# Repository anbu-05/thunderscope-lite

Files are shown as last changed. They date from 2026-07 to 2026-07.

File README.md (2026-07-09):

ad9288 can be replaced with ad9218 for higher resolution

the AFE is designed for 1GSPS so 100MSPS should work just fine

the STM32H523RETx can be replaced with STM32H562RGTx for higher performance

also you NEED to implement the microcontroller IC in the PCB because you need to make sure the all 8/10 of the ADC's output signals arrive at the same time

ad9288/9218 have different sampling rate options - but this requires changing out the CMOS oscillator accordinly as well. the current option is for a low jitter 100MHz clk signal: ASEM1-100.000MHZ-LC-T

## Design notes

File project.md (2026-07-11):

# thunderscope-lite Project Notes

## Current status

- `thunderscope-lite` is a KiCad 9 project at the repo root.
- Custom/project KiCad libraries have been vendored into `thunderscope-lite/libraries/`.
- Local library tables now point the existing schematic library names at the vendored files:
  - `sym-lib-table`
  - `fp-lib-table`
- Standard KiCad libraries such as `Device`, `power`, `Connector`, `Diode`, `Resistor_SMD`, `Capacitor_SMD`, and `Package_TO_SOT_SMD` are still expected from the installed KiCad library set.

## Vendored libraries

- Symbols are in `libraries/symbols/`.
- Footprints are in `libraries/footprints/`.
- Available custom 3D models are in `libraries/3dmodels/`.
- `AD9288BSTZ-40` and `ADA4930-2YCPZ-R2` footprints reference local STEP files through `${KIPRJMOD}`.
- `731000105.zip` and `UD2-4.5NUN-L.zip` do not contain STEP or WRL models, so no 3D models were available for those parts.

## Notes

- The project keeps existing library names like `AD9288BSTZ-40`, `ADA4930-2YCPZ-R2`, `UD2-4.5NUN-L`, `731000105`, and `Thunderscope_Rev5`.
- The `Thunderscope_Rev5` footprint library now contains the full Rev5.3 project footprint set, currently 61 `.kicad_mod` files.
- KiCad lock file `~thunderscope-lite.kicad_sch.lck` existed before this library work and was left alone.
- KiCad ERC was run on 2026-07-07 and completed without missing-library errors. It reported 108 existing schematic ERC violations, mostly unconnected pins and power pins not driven.
- While this was being edited, KiCad appears to have generated/updated autosave files and a backup zip. These were left untouched.
- 2026-07-11: Initial TL33/TL330 search did not find the library. It was later found as `TL3342F160QG.zip` and imported below.

## 2026-07-08 update

- Copied the full Rev5.3 project footprint library from `ThunderScope/Hardware/Thunderscope_Rev5.3/Thunderscope_Rev5.3.pretty/` into `libraries/footprints/Thunderscope_Rev5.pretty/`.
- Refreshed `libraries/symbols/Thunderscope_Rev5.kicad_sym` from Rev5.3.
- The lite project still uses the library name `Thunderscope_Rev5`; only the local library contents were expanded.

## 2026-07-08 STEP model note

- Rev5.3 does not store its 3D models as loose `.step`, `.stp`, or `.wrl` files in the project tree.
- The Rev5.3 3D models are embedded inside the copied `.kicad_mod` footprint files and referenced with `kicad-embed://...`.
- Fixed the lite copy of `FUJ_FTR-B3SA.kicad_mod` to reference its embedded `FTR-B3SA4.5Z.stp` model instead of the old Windows absolute path.

## 2026-07-08 KiCad library visibility note

- Adding `THUNDER_*` path variables in KiCad Configure Paths does not by itself make symbols or footprints appear in the chooser.
- KiCad loads project libraries from `sym-lib-table` and `fp-lib-table` in the project folder.
- Open `thunderscope-lite.kicad_pro`, then use Preferences -> Manage Symbol Libraries / Manage Footprint Libraries and check the Project Specific tab if vendored libraries do not appear.

## 2026-07-08 embedded model question

- Asked whether the AD9288 and AD4390 STEP files can be embedded into their footprint files.
- AD9288 has a loose STEP file in `libraries/3dmodels/`.
- No AD4390 library has been identified in the project; this may mean `ADA4930-2YCPZ-R2`.
- KiCad 9 footprints can embed 3D model files using `embedded_files` and `kicad-embed://...`, as seen in the copied Rev5.3 footprints.

## 2026-07-08 embedded_files format note

- KiCad 9 footprint embedded models are stored in an `(embedded_files ...)` block inside the `.kicad_mod` file.
- Each embedded file uses `(file (name "...") (type ...) (data |...|) (checksum "..."))`.
- The footprint 3D model entry references the embedded payload with `(model "kicad-embed://filename.step" ...)`.

## 2026-07-11 TL3342F160QG import

- Imported `TL3342F160QG.zip` from `/home/anbu/Downloads`.
- Added symbol library: `libraries/symbols/TL3342F160QG.kicad_sym`.
- Added footprint library: `libraries/footprints/TL3342F160QG.pretty/SW_TL3342F160QG.kicad_mod`.
- Added 3D model: `libraries/3dmodels/TL3342F160QG.step`.
- Registered `TL3342F160QG` in project `sym-lib-table` and `fp-lib-table`.
- Added a project-relative STEP model reference to the footprint using `${KIPRJMOD}/libraries/3dmodels/TL3342F160QG.step`.
- KiCad CLI `fp upgrade` parsed the new footprint library successfully. KiCad ERC loads the project without missing-library messages, but the schematic still has existing ERC violations.

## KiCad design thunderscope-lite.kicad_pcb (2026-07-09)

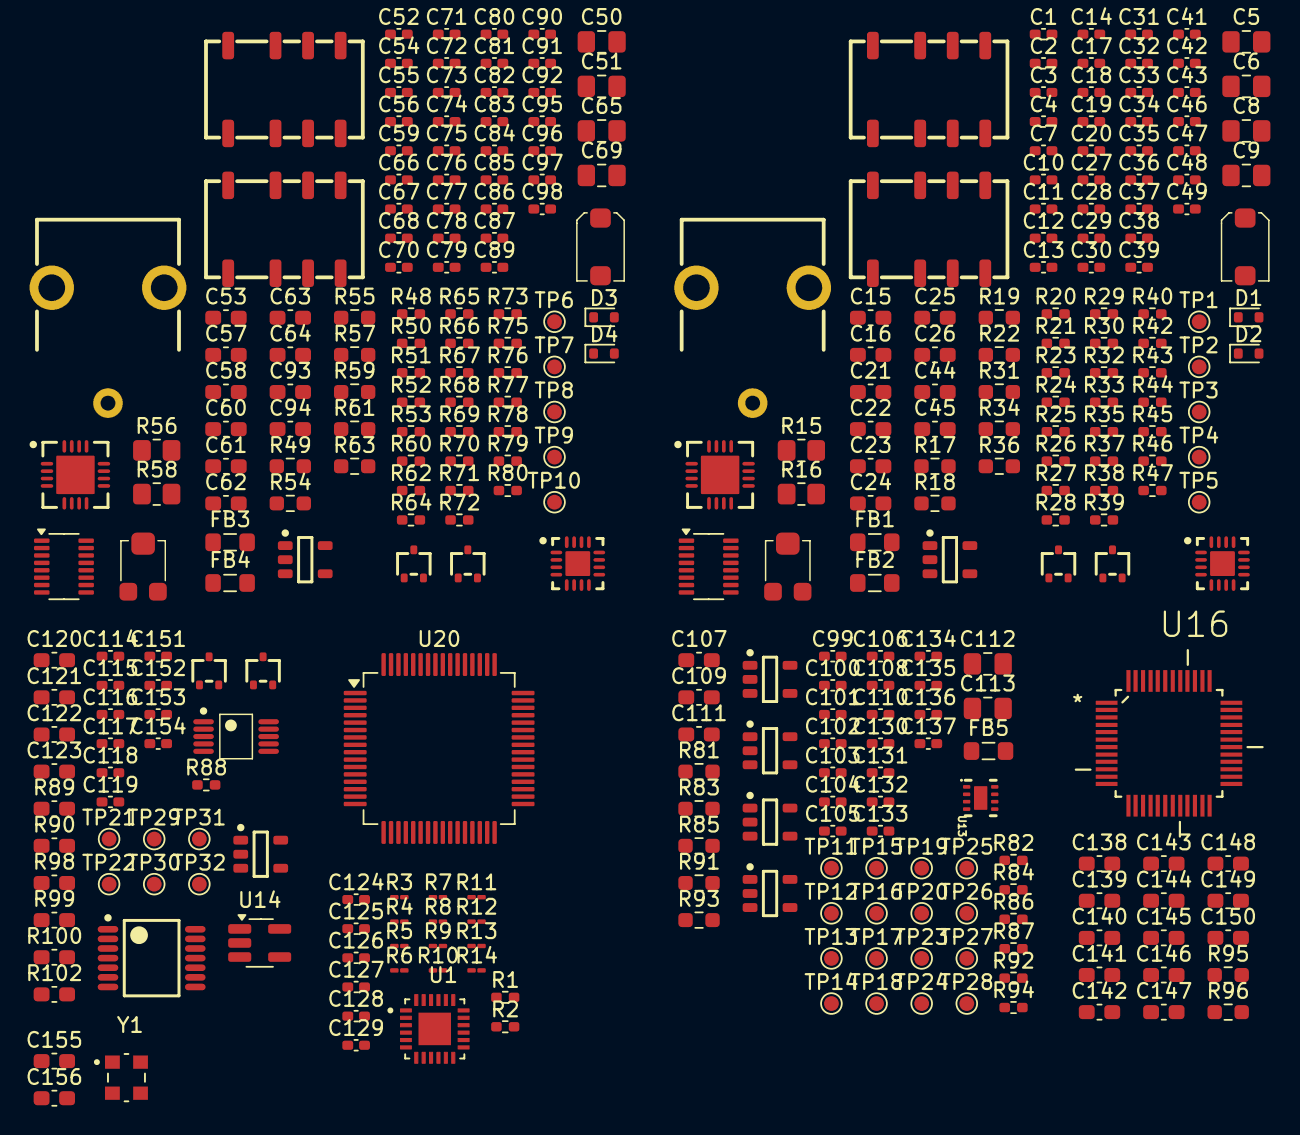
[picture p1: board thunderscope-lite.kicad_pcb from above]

Board: 2 copper layers, 330 parts (0 on the bottom side), 150 nets, no tracks yet.

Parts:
C1, C56: 18pF; C_0402_1005Metric_Pad0.74x0.62mm_HandSolder
C2, C3, C13, C77, C80, C87: 3pF; C_0402_1005Metric_Pad0.74x0.62mm_HandSolder
C4, C81: 0.3pF; C_0402_1005Metric_Pad0.74x0.62mm_HandSolder
C5, C6, C8, C9, C50, C51, C65, C69: 22uF; C_0805_2012Metric_Pad1.18x1.45mm_HandSolder
C7, C10, C27, C28, C29, C30, C31, C32, C33, C34, C35, C36, C37, C38, C39, C46, C47, C48, C49, C52, C66, C67, C70, C71, C72, C73, C74, C75, C76, C78, C79, C82, C83, C85, C95, C96, C97, C98, C101, C102, C105, C106, C115, C116, C117, C124, C125, C126, C127, C128, C132, C133, C136, C137, C152, C154: 1uF; C_0402_1005Metric_Pad0.74x0.62mm_HandSolder
C11, C86: 1pF; C_0402_1005Metric_Pad0.74x0.62mm_HandSolder
C12, C84: 8pF; C_0402_1005Metric_Pad0.74x0.62mm_HandSolder
C14, C41, C42, C43, C89, C90, C91, C92, C118: 100nF; C_0402_1005Metric_Pad0.74x0.62mm_HandSolder
C15, C60: 1nF; C_0603_1608Metric_Pad1.08x0.95mm_HandSolder
C16, C53: 10nF; C_0603_1608Metric_Pad1.08x0.95mm_HandSolder
C17, C18, C20, C54, C59, C68, C119: 100pF; C_0402_1005Metric_Pad0.74x0.62mm_HandSolder
C19, C55: 68pF; C_0402_1005Metric_Pad0.74x0.62mm_HandSolder
C21, C22, C23, C24, C25, C26, C44, C45, C57, C58, C61, C62, C63, C64, C93, C94, C107, C109, C111, C120, C122, C141, C142, C156: 10uF; C_0603_1608Metric_Pad1.08x0.95mm_HandSolder
C40, C88: 2-6pF; EW_TRIMCAP
C99, C100, C103, C104, C108, C110, C114, C129, C130, C131, C134, C135, C151, C153: 10uF; C_0402_1005Metric_Pad0.74x0.62mm_HandSolder
C112, C113: 10uF; C_0805_2012Metric_Pad1.18x1.45mm_HandSolder
C121, C123: 1uF; C_0603_1608Metric_Pad1.08x0.95mm_HandSolder
C138, C139, C140, C143, C144, C145, C146, C147, C148, C149, C150: 100nF; C_0603_1608Metric_Pad1.08x0.95mm_HandSolder
C155: 0.1uF; C_0603_1608Metric_Pad1.08x0.95mm_HandSolder
D1, D2, D3, D4: 1N4148WT; D_SOD-523
FB1, FB2, FB3, FB4, FB5: 120@100MHZ; L_0805_2012Metric_Pad1.05x1.20mm_HandSolder
J1, J2: BNC; MOL_0731000105
K1, K2, K3, K4: UD2-4.5NUN-L; KEMET_UD2-4.5NUN-L
Q1, Q2, Q3, Q4, Q5, Q6: DMN62D0UW; GEN_SOT_323
R1, R2: 300R; R_0402_1005Metric_Pad0.72x0.64mm_HandSolder
R3, R4, R5, R6, R7, R8: 300R; R_01005_0402Metric_Pad0.57x0.30mm_HandSolder
R9, R10: 120R; R_01005_0402Metric_Pad0.57x0.30mm_HandSolder
R11, R12, R13, R14: 4.99R; R_01005_0402Metric_Pad0.57x0.30mm_HandSolder
R15, R56: 49.9R; R_0805_2012Metric_Pad1.20x1.40mm_HandSolder
R16, R58: 1MR; R_0805_2012Metric_Pad1.20x1.40mm_HandSolder
R17, R31, R55, R57: 30R; R_0603_1608Metric_Pad0.98x0.95mm_HandSolder
R18, R59: 15R; R_0603_1608Metric_Pad0.98x0.95mm_HandSolder
R19, R22, R49, R63: 22R; R_0603_1608Metric_Pad0.98x0.95mm_HandSolder
R20, R21, R23, R24, R52, R53, R64, R65: 10KR; R_0402_1005Metric_Pad0.72x0.64mm_HandSolder
R25, R46, R47, R60, R79, R80: 0R; R_0402_1005Metric_Pad0.72x0.64mm_HandSolder
R26, R43, R44, R66, R76, R77: 1K; R_0402_1005Metric_Pad0.72x0.64mm_HandSolder
R27, R28, R67, R68: 976K; R_0402_1005Metric_Pad0.72x0.64mm_HandSolder
R29, R70: 20K; R_0402_1005Metric_Pad0.72x0.64mm_HandSolder
R30, R50: 909K; R_0402_1005Metric_Pad0.72x0.64mm_HandSolder
R32, R38, R40, R51, R71, R75, R87: 90.9K; R_0402_1005Metric_Pad0.72x0.64mm_HandSolder
R33, R39, R45, R48, R72, R78, R82, R84, R92, R94: 10K; R_0402_1005Metric_Pad0.72x0.64mm_HandSolder
R34, R36, R54, R61: 10M; R_0603_1608Metric_Pad0.98x0.95mm_HandSolder
R35, R62: 2K; R_0402_1005Metric_Pad0.72x0.64mm_HandSolder
R37, R69: 35.7K; R_0402_1005Metric_Pad0.72x0.64mm_HandSolder
R41, R74: 2K TRIMPOT; BOU_3mm_POT
R42, R73: 49.9K; R_0402_1005Metric_Pad0.72x0.64mm_HandSolder
R81, R83, R85, R91, R93: 0.01R; R_0603_1608Metric_Pad0.98x0.95mm_HandSolder
R86: 280K; R_0402_1005Metric_Pad0.72x0.64mm_HandSolder
R88: 100R; R_0402_1005Metric_Pad0.72x0.64mm_HandSolder
R89, R90: 10K; C_0603_1608Metric_Pad1.08x0.95mm_HandSolder
R95: 23.2K; R_0603_1608Metric_Pad0.98x0.95mm_HandSolder
R96: 10K; R_0603_1608Metric_Pad0.98x0.95mm_HandSolder
R98, R99, R100, R102: 4.7K; C_0603_1608Metric_Pad1.08x0.95mm_HandSolder
TP1, TP2, TP3, TP4, TP5, TP6, TP7, TP8, TP9, TP10, TP11, TP12, TP13, TP14, TP15, TP16, TP17, TP18, TP19, TP20, TP21, TP22, TP23, TP24, TP25, TP26, TP27, TP28, TP29, TP30, TP31, TP32: TestPoint; TestPoint_Pad_D1.0mm
U1: ADA4930-2YCPZ-R2; QFN50P400X400X100-25N
U2: MCP4728; MC_MSOP10_UN
U3, U7: TMUX4053; TI_TSOT-23-16_DYY0016A
U4, U8, U15: OPA140AIDBVR; GEN_SOT23_5_950_2900X1600X1450
U5, U9: BUF802; TI_VQFN_RGT0016C
U6, U10: LMH6518; TI_WQFN_RGH0016A
U11, U12, U17, U18: NCP161ASN330T1G; GEN_SOT23_5_950_2900X1600X1450
U13: LM27761; TI_WSON8_DSG0008A
U14: REF2025; SOT-23-5_HandSoldering
U16: AD9218BSTZ-105; QFP50P900X900X160-48N
U19: MCP4452-104E; MC_TSSOP14
U20: STM32H562RGTx; LQFP-64_10x10mm_P0.5mm
Y1: ASEM1-100.000MHZ-LC-T; XTAL_ASEM1-100.000MHZ-LC-T

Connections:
+3V3_ACQ: C101.1, C102.1, C126.1, C127.1, C128.1, C129.1, TP13.1, U1.3 (+VS1), U1.4 (+VS1), U1.9 (+VS2), U1.10 (+VS2), U1.14 (*PD2), U1.20 (*PD1), U11.5 (OUT)
+3V3_PGA: C49.2, C98.2, Q3.2 (G), Q4.2 (G), R45.2, R78.2, R99.1, R100.1, U6.12 (VDD), U10.12 (VDD)
+3V3_VD: C132.1, C133.1, C142.2, C144.2, C146.2, C148.2, C150.2, R95.1, TP25.1, U16.13 (VD_2), U16.30 (VD_3), U16.31 (VD), U16.48 (VD_4), U17.5 (OUT)
+3V3_VDD: C136.1, C137.1, C141.1, C143.1, C145.1, C147.1, C149.1, C155.1, C156.1, TP28.1, U16.15 (VDD), U16.28 (VDD_3), U16.33 (VDD_2), U16.46 (VDD_4), U18.5 (OUT), Y1.1 (STANDBY), Y1.4 (VDD)
+5V: C5.1, C8.1, C21.2, C22.2, C23.2, C27.2, C28.2, C29.2, C30.2, C31.2, C32.2, C39.2, C44.2, C50.1, C57.2, C61.2, C63.2, C65.1, C66.2, C70.2, C73.2, C75.2, C78.2, C82.2, C85.2, C93.2, C114.1, C115.1, C120.1, C121.1, C151.1, C152.1, C153.1, C154.1, FB2.1, FB4.1, R19.1, R22.1, R49.1, R63.1, R81.1, R83.1, R85.1, R91.1, R93.1, R98.1, R102.1, TP11.1, TP14.1, TP17.1, TP23.1, TP26.1, U2.1 (VDD), U3.16 (VDD), U4.5 (V+), U5.1 (Vs+), U5.12 (Vso+), U5.15 (CLH), U7.16 (VDD), U8.5 (V+), U9.1 (Vs+), U9.12 (Vso+), U9.15 (CLH), U14.3 (EN), U14.4 (IN), U15.5 (V+), U19.12 (VDD)
+VBIAS: C117.1, R89.2, TP21.1, U14.5 (Vref)
-5V: C24.1, C25.1, C26.1, C33.1, C34.1, C35.1, C36.1, C37.1, C38.1, C58.1, C62.1, C64.1, C67.1, C71.1, C74.1, C76.1, C79.1, C83.1, C110.1, C112.1, C113.1, C122.2, C123.2, FB5.2, R37.1, R69.1, TP20.1, U3.7 (VSS), U4.2 (V-), U5.5 (Vs-), U5.6 (Aux_Bias), U5.8 (Vs-), U5.10 (Vso-), U7.7 (VSS), U8.2 (V-), U9.5 (Vs-), U9.6 (Aux_Bias), U9.8 (Vs-), U9.10 (Vso-), U15.2 (V-)
-VBIAS: C14.2, C41.2, C89.2, C91.2, C118.1, R40.1, R43.2, R44.2, R75.1, R76.2, R77.2, R88.1, TP22.1
/ACQ and FE Voltage Regs/+5V_R_CP: C107.1, R85.2, TP18.1, U13.1 (VIN)
/ACQ and FE Voltage Regs/ACQ_EN: R82.2, U11.3 (EN)
/ACQ and FE Voltage Regs/PGA_EN: R84.2, U12.3 (EN)
/ACQ and FE Voltage Regs/VDD_EN: R94.2, U18.3 (EN)
/ACQ and FE Voltage Regs/VD_EN: R92.2, U17.3 (EN)
/ADC driver/IN1_N: R3.1, R9.1, R47.1
/ADC driver/IN1_P: R2.1, R9.2, R46.1
/ADC driver/IN2_N: R7.1, R10.1, R80.1
/ADC driver/IN2_P: R6.1, R10.2, R79.1
/ADC driver/OUT1_N: R11.2, U16.3 (~AINA)
/ADC driver/OUT1_P: R12.2, U16.2 (AINA)
/ADC driver/OUT2_N: R13.2, U16.10 (~AINB)
/ADC driver/OUT2_P: R14.2, U16.11 (AINB)
/ADC/ENC: U16.14 (ENCB), U16.47 (ENCA), Y1.3 (OUTPUT)
/CH1/+VPGA: C45.2, C46.2, C47.2, C48.2, FB2.2, U6.3 (VCC), U6.4 (VCC)
/CH1/ATTEN: R23.2, R24.1, TP2.1
/CH1/ATTEN_1X: K1.4, K1.5
/CH1/ATTEN_50X_IN: C3.2, C4.2, K1.2, R26.2, R27.2
/CH1/ATTEN_50X_OUT: C11.1, C13.1, C40.1, K1.7, R27.1, R29.1
/CH1/ATTEN_IN: K1.3, K3.6
/CH1/ATTEN_OUT: K1.6, R30.2, R31.1
/CH1/BNC_IN: J2.1 (Signal), K3.3
/CH1/BUF_IN: C15.2, R36.1, U5.2 (IN)
/CH1/BUF_IN_AUX: C20.2, R35.2, U5.4 (IN_Aux)
/CH1/BUF_IN_BIAS: R36.2, U5.3 (IN_Bias)
/CH1/BUF_OUT: R38.2, R42.2, U5.11 (OUT)
/CH1/BUF_OUT_R: R42.1, U6.6 (IN_P)
/CH1/DC_CPL: R33.2, TP3.1, U3.9 (SEL3), U3.10 (SEL2), U3.11 (SEL1)
/CH1/DC_FB: C17.1, U3.15 (D2), U4.4 (-)
/CH1/PGA_BIAS: C43.2, FB1.2, R43.1, R44.1, TP4.1, U6.7 (IN_N)
/CH1/PGA_CSn: R45.1, TP5.1, U6.9 (CSn)
/CH1/TERM: R20.1, R21.2, TP1.1
/CH1/TERM_1M: K3.2, R17.1
/CH1/TERM_50Z: C1.1, K3.4, R15.1, R18.1
/CH1/TERM_50Z_R: K3.5, R18.2, R25.2
/CH2/+VPGA: C94.2, C95.2, C96.2, C97.2, FB4.2, U10.3 (VCC), U10.4 (VCC)
/CH2/ATTEN: R64.2, R65.1, TP8.1
/CH2/ATTEN_1X: K4.4, K4.5
/CH2/ATTEN_50X_IN: C80.2, C81.2, K4.2, R66.2, R67.2
/CH2/ATTEN_50X_OUT: C86.1, C87.1, C88.1, K4.7, R67.1, R70.1
/CH2/ATTEN_IN: K2.6, K4.3
/CH2/ATTEN_OUT: K4.6, R50.2, R57.1
/CH2/BNC_IN: J1.1 (Signal), K2.3
/CH2/BUF_IN: C60.2, R61.1, U9.2 (IN)
/CH2/BUF_IN_AUX: C68.2, R62.2, U9.4 (IN_Aux)
/CH2/BUF_IN_BIAS: R61.2, U9.3 (IN_Bias)
/CH2/BUF_OUT: R71.2, R73.2, U9.11 (OUT)
/CH2/BUF_OUT_R: R73.1, U10.6 (IN_P)
/CH2/DC_CPL: R48.2, TP6.1, U7.9 (SEL3), U7.10 (SEL2), U7.11 (SEL1)
/CH2/DC_FB: C59.1, U7.15 (D2), U8.4 (-)
/CH2/PGA_BIAS: C92.2, FB3.2, R76.1, R77.1, TP10.1, U10.7 (IN_N)
/CH2/PGA_CSn: R78.1, TP9.1, U10.9 (CSn)
/CH2/TERM: R52.2, R53.1, TP7.1
/CH2/TERM_1M: K2.2, R55.1
/CH2/TERM_50Z: C56.1, K2.4, R56.1, R59.1
/CH2/TERM_50Z_R: K2.5, R59.2, R60.2
/Front End Trim and Bias/TRIM_SCL: Q4.3 (S), R99.2, TP31.1
/Front End Trim and Bias/TRIM_SCL_5V: Q4.1 (D), R102.2, TP29.1, U2.2 (SCL), U19.4 (SCL)
/Front End Trim and Bias/TRIM_SDA: Q3.3 (S), R100.2, TP32.1
/Front End Trim and Bias/TRIM_SDA_5V: Q3.1 (D), R98.2, TP30.1, U2.3 (SDA), U19.5 (SDA)
/Front End Trim and Bias/US-: C119.1, R89.1, R90.2, U15.3 (+)
/Front End Trim and Bias/VOUT1: U2.6 (VOUTA), U19.13 (P2B)
/Front End Trim and Bias/VOUT2: U2.7 (VOUTB), U19.10 (P0B)
/Front End Trim and Bias/VOUT3: U2.8 (VOUTC), U19.7 (P1B)
/Front End Trim and Bias/VOUT4: U2.9 (VOUTD), U19.2 (P3B)
/TRIM_1: C42.2, FB1.1, U19.14 (P2W)
/TRIM_2: C90.2, FB3.1, U19.9 (P0W)
/VCM: C124.1, C125.1, R95.2, R96.1, U1.11 (VOCM2), U1.17 (VOCM1), U6.13 (VCM), U10.13 (VCM)
GND: C2.1, C5.2, C6.2, C7.2, C8.2, C9.2, C10.2, C12.2, C13.2, C14.1, C20.1, C21.1, C22.1, C23.1, C24.2, C25.2, C26.2, C27.1, C28.1, C29.1, C30.1, C31.1, C32.1, C33.2, C34.2, C35.2, C36.2, C37.2, C38.2, C39.1, C40.2, C41.1, C42.1, C43.1, C44.1, C45.1, C46.1, C47.1, C48.1, C49.1, C50.2, C51.2, C52.2, C57.1, C58.2, C61.1, C62.2, C63.1, C64.2, C65.2, C66.1, C67.2, C68.1, C69.2, C70.1, C71.2, C72.2, C73.1, C74.2, C75.1, C76.2, C77.1, C78.1, C79.2, C82.1, C83.2, C84.2, C85.1, C87.2, C88.2, C89.1, C90.1, C91.1, C92.1, C93.1, C94.1, C95.1, C96.1, C97.1, C98.1, C99.2, C100.2, C101.2, C102.2, C103.2, C104.2, C105.2, C106.2, C107.2, C109.2, C110.2, C111.2, C112.2, C113.2, C114.2, C115.2, C116.2, C117.2, C118.2, C120.2, C121.2, C122.1, C123.1, C124.2, C125.2, C126.2, C127.2, C128.2, C129.2, C130.2, C131.2, C132.2, C133.2, C134.2, C135.2, C136.2, C137.2, C138.2, C139.2, C140.2, C141.2, C142.1, C143.2, C144.1, C145.2, C146.1, C147.2, C148.1, C149.2, C150.1, C151.2, C152.2, C153.2, C154.2, C155.2, C156.2, J1.2 (SHIELD), J2.2 (SHIELD), Q1.3 (S), Q2.3 (S), Q5.3 (S), Q6.3 (S), R15.2, R16.2, R21.1, R23.1, R29.2, R32.1, R33.1, R34.1, R41.3, R48.1, R51.1, R52.1, R54.1, R56.2, R58.2, R64.1, R70.2, R74.3, R82.1, R84.1, R87.1, R92.1, R94.1, R96.2, U1.15 (-VS2), U1.16 (-VS2), U1.21 (-VS1), U1.22 (-VS1), U1.25 (EPAD), U2.4 (LDACn), U2.10 (VSS), U3.6 (~EN), U3.8 (GND), U5.14 (CLL), U5.17 (PAD), U6.5 (GND), U6.8 (GND), U6.17 (PAD), U7.6 (~EN), U7.8 (GND), U9.14 (CLL), U9.17 (PAD), U10.5 (GND), U10.8 (GND), U10.17 (PAD), U11.2 (GND), U12.2 (GND), U13.2 (GND), U13.9 (PAD), U14.2 (GND), U15.4 (-), U16.1 (GND_7), U16.12 (GND_4), U16.16 (GND_6), U16.27 (GND_3), U16.29 (GND_8), U16.32 (GND_2), U16.34 (GND), U16.45 (GND_5), U17.2 (GND), U18.2 (GND), U19.3 (HVC/A0), U19.6 (VSS), U19.11 (A1), U20.12 (VSSA), U20.18 (VSS), U20.31 (VSS), U20.47 (VSS), U20.63 (VSS), Y1.2 (GND)
unnamed: C1.2, R25.1
unnamed: C2.2, R26.1
unnamed: C4.1, R28.2
unnamed: C3.1, C11.2, C12.1, R28.1
unnamed: C15.1, R31.2
unnamed: C56.2, R60.1
unnamed: C60.1, R57.2
unnamed: C77.2, R66.1
unnamed: C80.1, C84.1, C86.2, R68.1
unnamed: C81.1, R68.2
unnamed: D1.2 (A), K3.8, Q5.1 (D)
unnamed: C6.1, C7.1, D1.1 (K), K3.1, R19.2
unnamed: D2.2 (A), K1.8, Q1.1 (D)
unnamed: C9.1, C10.1, D2.1 (K), K1.1, R22.2
unnamed: D3.2 (A), K2.8, Q6.1 (D)
unnamed: C51.1, C52.1, D3.1 (K), K2.1, R49.2
unnamed: D4.2 (A), K4.8, Q2.1 (D)
unnamed: C69.1, C72.1, D4.1 (K), K4.1, R63.2
unnamed: K2.7, R55.2, R58.1
unnamed: K3.7, R16.1, R17.2
unnamed: Q1.2 (G), R24.2
unnamed: Q2.2 (G), R65.2
unnamed: Q5.2 (G), R20.2
unnamed: Q6.2 (G), R53.2
unnamed: R38.1, R39.2, R40.2
unnamed: R39.1, R41.1, R41.2
unnamed: R71.1, R72.2, R75.2
unnamed: R72.1, R74.1, R74.2
unnamed: R4.2, U1.2 (+FB1)
unnamed: R8.2, U1.8 (+FB2)
unnamed: R1.1, R2.2, U1.24 (+IN1)
unnamed: R5.1, R6.2, U1.6 (+IN2)
unnamed: R14.1, U1.18 (+OUT1)
unnamed: R12.1, U1.12 (+OUT2)
unnamed: R1.2, U1.23 (-FB1)
unnamed: R5.2, U1.5 (-FB2)
unnamed: R3.2, R4.1, U1.1 (-IN1)
unnamed: R7.2, R8.1, U1.7 (-IN2)
unnamed: R13.1, U1.19 (-OUT1)
unnamed: R11.1, U1.13 (-OUT2)
unnamed: C16.1, R30.1, R32.2, U3.14 (D1)
unnamed: C17.2, R35.1, U3.4 (D3), U4.1 (OUT)
unnamed: C16.2, R34.2, U3.13 (S1B), U4.3 (+)
unnamed: C18.1, U3.2 (S2A)
unnamed: C19.1, U3.1 (S2B)
unnamed: C18.2, U3.5 (S3A)
unnamed: C19.2, U3.3 (S3B)
unnamed: R37.2, U5.7 (R_Bias)
unnamed: R47.2, U6.14 (OUT_N)
unnamed: R46.2, U6.15 (OUT_P)
unnamed: C53.1, R50.1, R51.2, U7.14 (D1)
unnamed: C59.2, R62.1, U7.4 (D3), U8.1 (OUT)
unnamed: C53.2, R54.2, U7.13 (S1B), U8.3 (+)
unnamed: C54.1, U7.2 (S2A)
unnamed: C55.1, U7.1 (S2B)
unnamed: C54.2, U7.5 (S3A)
unnamed: C55.2, U7.3 (S3B)
unnamed: R69.2, U9.7 (R_Bias)
unnamed: R80.2, U10.14 (OUT_N)
unnamed: R79.2, U10.15 (OUT_P)
unnamed: C99.1, C100.1, R81.2, TP12.1, U11.1 (IN)
unnamed: C103.1, C104.1, R83.2, TP15.1, U12.1 (IN)
unnamed: C108.1, U13.8 (C1+)
unnamed: C108.2, U13.7 (C1-)
unnamed: C109.1, U13.3 (CPOUT)
unnamed: R86.1, R87.2, U13.5 (VFB)
unnamed: C111.1, FB5.1, R86.2, TP19.1, U13.4 (VOUT)
unnamed: C116.1, U14.1 (Vbias)
unnamed: C119.2, R88.2, R90.1, U15.1 (OUT)
unnamed: C138.1, C139.1, C140.1, U16.5 (REFINA), U16.6 (REFOUT), U16.7 (REFINB)
unnamed: C130.1, C131.1, R91.2, TP24.1, U17.1 (IN)
unnamed: C134.1, C135.1, R93.2, TP27.1, U18.1 (IN)
PGA: C105.1, C106.1, TP16.1, U12.5 (OUT)

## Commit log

2026-07-07 finished the FE channel and voltage generation
    [FE_channel.kicad_sch, thunderscope-lite.kicad_sch, voltage_gen.kicad_sch]
2026-07-08 updated the resistor sizings from all 0805 to 0402, 0603 and 0805s, to match the thunderscope directly
    [ADC_driver.kicad_sch, FE_channel.kicad_sch, thunderscope-lite.kicad_pcb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]
2026-07-09 added ADC, added FE trim. now all that's left is the micromicrocontroller
    [ACQ_FE_VREG.kicad_sch, ADC.kicad_sch, FE.kicad_sch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]
2026-07-09 decided on clk source and MCU
    [ACQ_FE_VREG.kicad_sch, ADC.kicad_sch, CLK.kicad_sch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]
2026-07-09 updated a few stuff
    [thunderscope-lite.kicad_pcb]
2026-07-11 almost done with the microcontroller, just need to connect t the AFE and ADC pins
    [MCU.kicad_sch, thunderscope-lite.kicad_sch]
2026-07-11 schematic complete. no ERC errors
    [ACQ_FE_VREG.kicad_sch, ADC.kicad_sch, ADC_driver.kicad_sch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]
